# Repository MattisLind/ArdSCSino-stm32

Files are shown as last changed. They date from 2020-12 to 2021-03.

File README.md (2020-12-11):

# ArdSCSino-stm32

The idea and the base code was taken from a project created by Tambo (TNB Seisakusho) (https://twitter.com/h_koma2) ArdSCSino is hardware that reproduces SCSI devices (hard disks) with arduino.

### Setup

I am using Arduino Software (IDE) V1.8.13.
Tools-> Boards-> Board Manager-> Search Filters Search and install "Arduino SAM board (32-bit ARM Cortex-M3)" Select the board "Generic STM32F103C series"

I am using the following as a library.

SDFAT (https://github.com/greiman/SdFat/tree/1.1.4) 

* Make sure to use V1 of SdFat (for example V1.1.4 )
* Make sure to set the #define ENABLE_EXTENDED_TRANSFER_CLASS 1 in SdFatConfig.h

Arduino_STM32 (https://github.com/rogerclarkmelbourne/Arduino_STM32/releases/tag/v1.0.0)

## Enhancements

In the STM32SCSISD folder there is a new PCB which integrates the following features:
* Floppy / AMP / TE connectivity connector.
* Pin headers for serial port, USB, SWD connectors. The use of these are for debugging only and is purely optional.
* Jumpers for RESET and BOOT. Also only needed for debuging.
* Jumpers for and image select. The image select feature allow for selecting one out of four images on the card when the SCSI device is selected.
* Jumpers for unit select. Allow the settig of the SCSI ID. The ID is also used to select one of seven sets of images as defined by the image select above.
* Activity LED pin header.
* Mounting holes.

The firmware (in STM32SCSISD_FW) has been improved by optimizing how data is transfered to the SCSI port. One SCSI transaction is now 1.2 microsseconds and the innerloop consists of 30 instructions. Please make sure that you use -O3 optimizations when compiling the project.

```
arm-none-eabi-g++ -mcpu=cortex-m3 -mthumb ArdSCSinoV2.cpp ../../SdFat/src/FatLib/FatFile.cpp  -I../../Arduino_STM32/STM32F1/libraries/SPI/src/ -I../../Arduino_STM32/STM32F1/system/libmaple/include/ -I../../Arduino_STM32/STM32F1/system/libmaple/ -I../../Arduino_STM32/STM32F1/cores/maple/ -I../../Arduino_STM32/STM32F1/variants/generic_stm32f103c -DMCU_STM32F103C8 -I../../Arduino_STM32/STM32F1/system/libmaple/stm32f1/include/ -I../../SdFat/src/ -DARDUINO -DF_CPU=72000000 -D__arm__ -D__STM32F1__ -Dnullptr=NULL -O3
```

Real life copying of 5 Mbyte file under RT-11 operating system running on a PDP-11/23 CPU takes 23 seconds which is equivalent of 218kbytes/s copying speed. Comparing this with the SCSI2SD v5 adapter gives a 305kbytes/s copying speed. 

The design has also been tested successfully with a Luxor ABC1600 computer.

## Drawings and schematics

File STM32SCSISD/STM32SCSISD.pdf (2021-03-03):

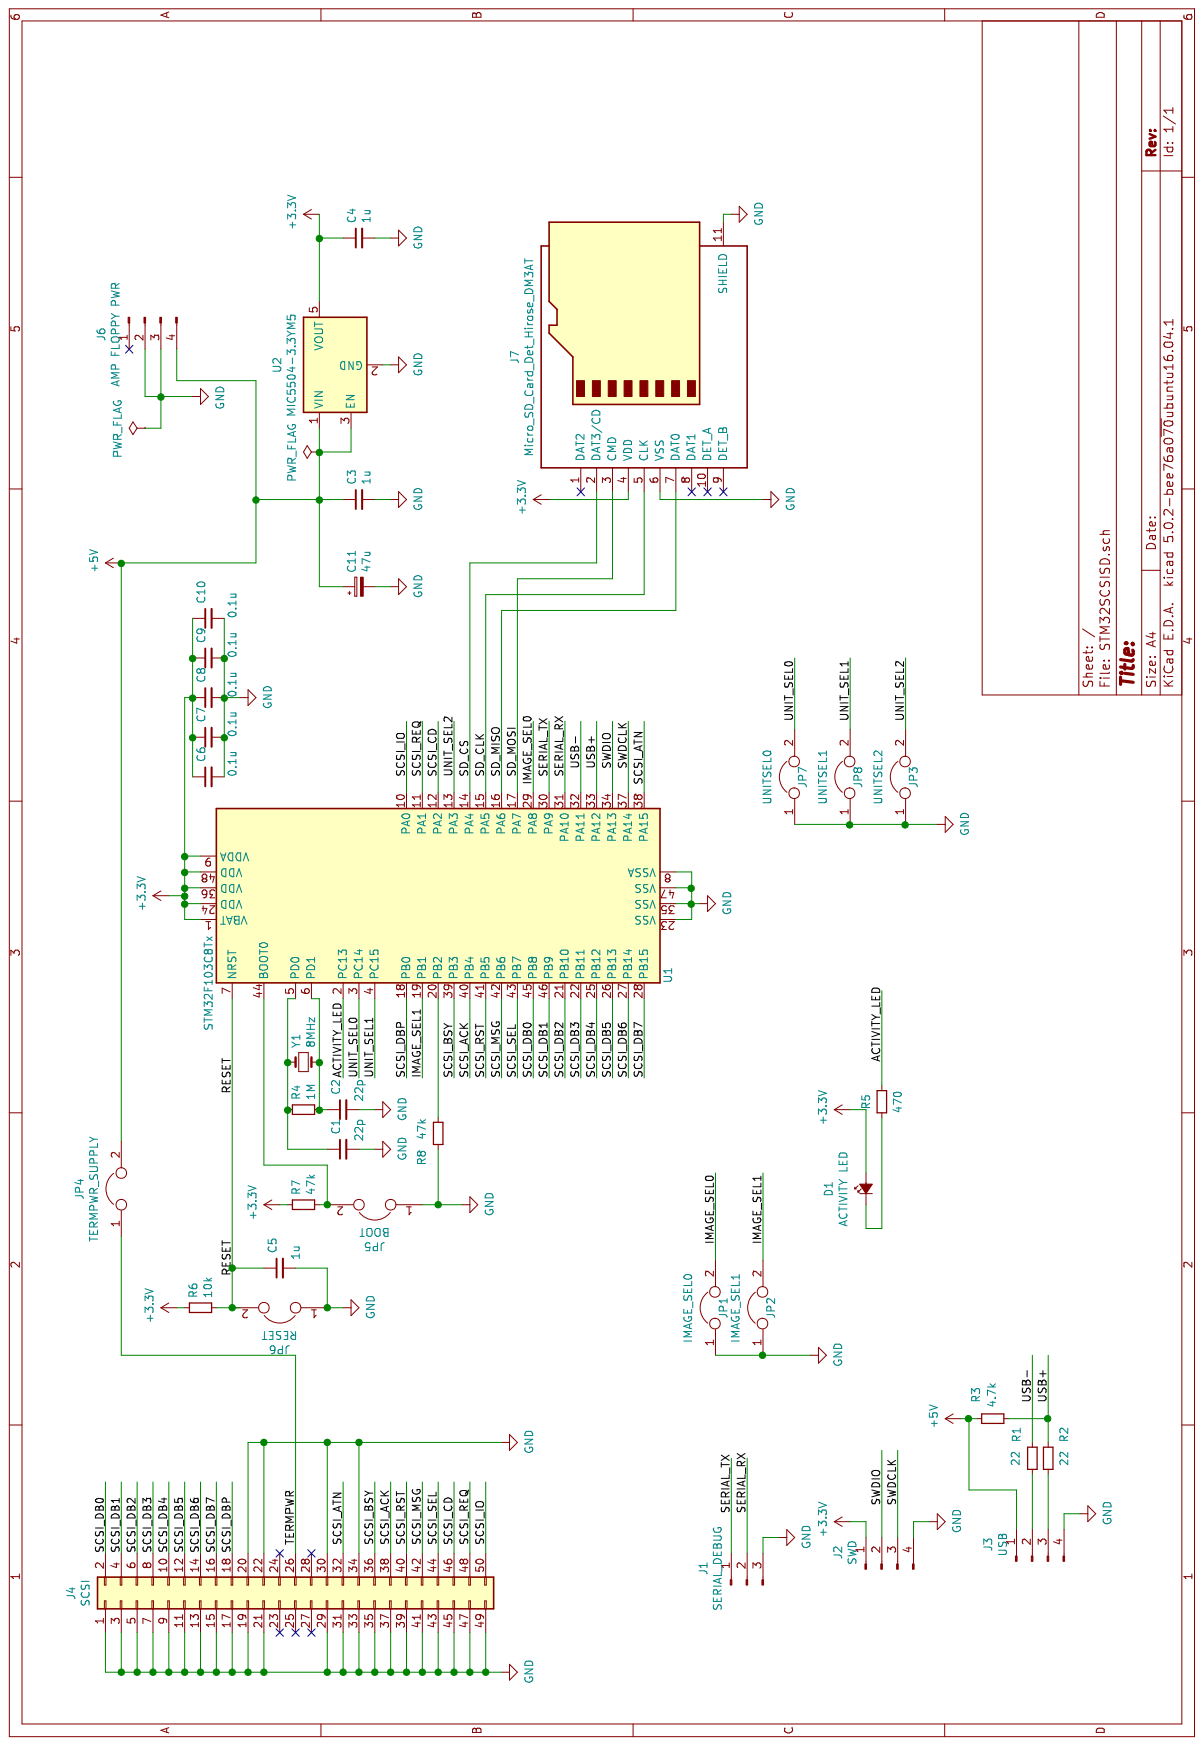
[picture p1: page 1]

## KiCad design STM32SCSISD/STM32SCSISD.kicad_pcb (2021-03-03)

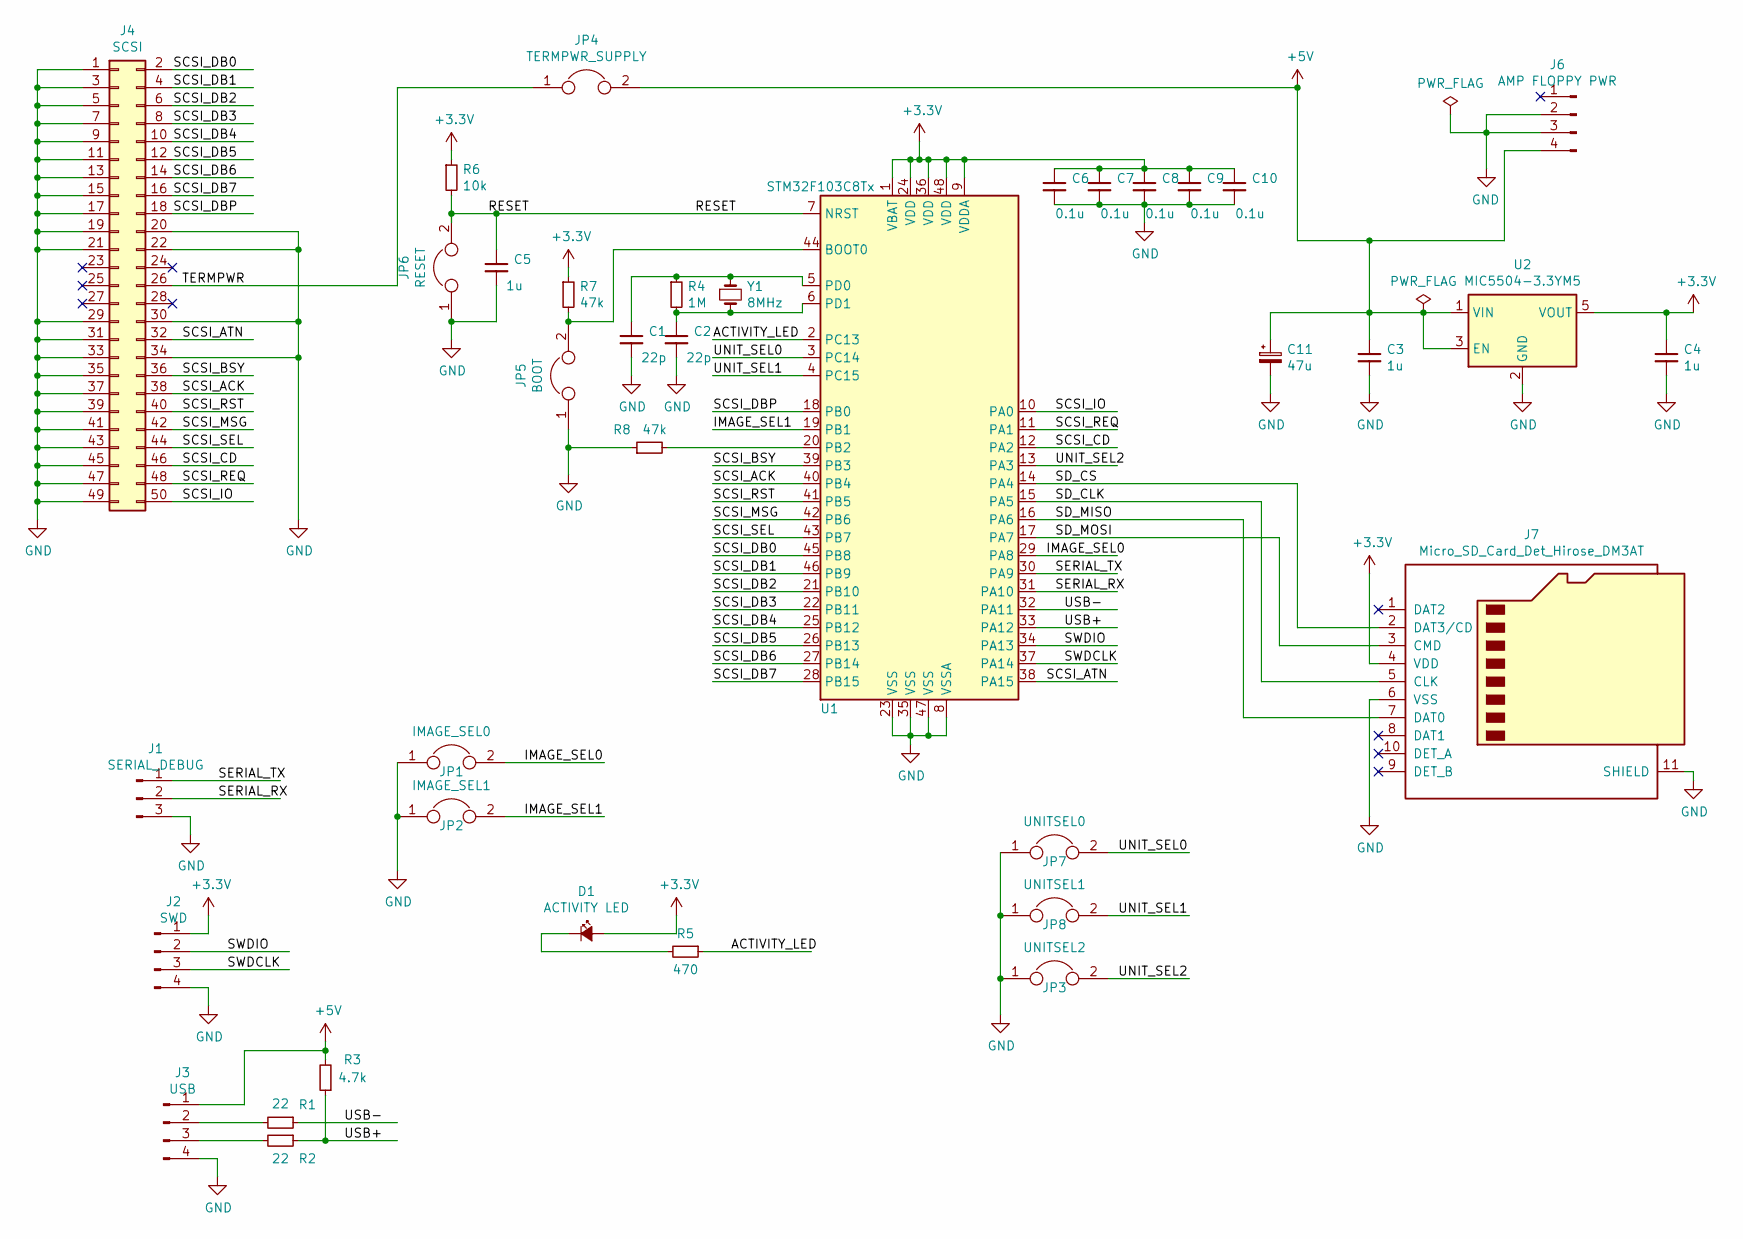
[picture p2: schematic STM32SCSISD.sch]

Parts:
C1, C2: 22p; C_0805_2012Metric
C3, C4, C5: 1u; C_0805_2012Metric
C6, C7, C8, C9, C10: 0.1u; C_0805_2012Metric
C11: 47u; CP_Radial_D5.0mm_P2.50mm
D1: ACTIVITY LED; LED_D5.0mm
J1: SERIAL_DEBUG; PinHeader_1x03_P2.54mm_Vertical
J2: SWD; PinHeader_1x04_P2.54mm_Vertical
J3: USB; PinHeader_1x04_P2.54mm_Vertical
J4: SCSI; IDC-Header_2x25_P2.54mm_Vertical
J6: AMP FLOPPY PWR; TE_MATE-N-LOK_350211-1_1x04_P5.08mm_Vertical
J7: Micro_SD_Card_Det_Hirose_DM3AT; microSD_HC_Hirose_DM3AT-SF-PEJM5
JP1: IMAGE_SEL0; PinHeader_1x02_P2.54mm_Vertical
JP2: IMAGE_SEL1; PinHeader_1x02_P2.54mm_Vertical
JP3: UNITSEL2; PinHeader_1x02_P2.54mm_Vertical
JP4: TERMPWR_SUPPLY; PinHeader_1x02_P2.54mm_Vertical
JP5: BOOT; PinHeader_1x02_P2.54mm_Vertical
JP6: RESET; PinHeader_1x02_P2.54mm_Vertical
JP7: UNITSEL0; PinHeader_1x02_P2.54mm_Vertical
JP8: UNITSEL1; PinHeader_1x02_P2.54mm_Vertical
R1, R2: 22; R_0805_2012Metric_Pad1.15x1.40mm_HandSolder
R3: 4.7k; R_0805_2012Metric_Pad1.15x1.40mm_HandSolder
R4: 1M; R_0805_2012Metric_Pad1.15x1.40mm_HandSolder
R5: 470; R_0805_2012Metric_Pad1.15x1.40mm_HandSolder
R6: 10k; R_0805_2012Metric_Pad1.15x1.40mm_HandSolder
R7, R8: 47k; R_0805_2012Metric_Pad1.15x1.40mm_HandSolder
U1: STM32F103C8Tx; LQFP-48_7x7mm_P0.5mm
U2: MIC5504-3.3YM5; SOT-23-5
Y1: 8MHz; Crystal_HC49-U_Vertical

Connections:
+3V3: C4.1, C6.1, C7.1, C8.1, C9.1, C10.1, D1.2 (A), J2.1, J7.4 (VDD), R6.1, R7.1, U1.1 (VBAT), U1.9 (VDDA), U1.24 (VDD), U1.36 (VDD), U1.48 (VDD), U2.5 (VOUT)
+5V: C3.1, C11.1, J3.1, J6.4, JP4.2, R3.2, U2.1 (VIN), U2.3 (EN)
/ACTIVITY_LED: R5.1, U1.2 (PC13)
/IMAGE_SEL0: JP1.2, U1.29 (PA8)
/IMAGE_SEL1: JP2.2, U1.19 (PB1)
/RESET: C5.1, JP6.2, R6.2, U1.7 (NRST)
/SCSI_ACK: J4.38, U1.40 (PB4)
/SCSI_ATN: J4.32, U1.38 (PA15)
/SCSI_BSY: J4.36, U1.39 (PB3)
/SCSI_CD: J4.46, U1.12 (PA2)
/SCSI_DB0: J4.2, U1.45 (PB8)
/SCSI_DB1: J4.4, U1.46 (PB9)
/SCSI_DB2: J4.6, U1.21 (PB10)
/SCSI_DB3: J4.8, U1.22 (PB11)
/SCSI_DB4: J4.10, U1.25 (PB12)
/SCSI_DB5: J4.12, U1.26 (PB13)
/SCSI_DB6: J4.14, U1.27 (PB14)
/SCSI_DB7: J4.16, U1.28 (PB15)
/SCSI_DBP: J4.18, U1.18 (PB0)
/SCSI_IO: J4.50, U1.10 (PA0)
/SCSI_MSG: J4.42, U1.42 (PB6)
/SCSI_REQ: J4.48, U1.11 (PA1)
/SCSI_RST: J4.40, U1.41 (PB5)
/SCSI_SEL: J4.44, U1.43 (PB7)
/SD_CLK: J7.5 (CLK), U1.15 (PA5)
/SD_CS: J7.2 (DAT3/CD), U1.14 (PA4)
/SD_MISO: J7.7 (DAT0), U1.16 (PA6)
/SD_MOSI: J7.3 (CMD), U1.17 (PA7)
/SERIAL_RX: J1.2, U1.31 (PA10)
/SERIAL_TX: J1.1, U1.30 (PA9)
/SWDCLK: J2.3, U1.37 (PA14)
/SWDIO: J2.2, U1.34 (PA13)
/TERMPWR: J4.26, JP4.1
/UNIT_SEL0: JP7.2, U1.3 (PC14)
/UNIT_SEL1: JP8.2, U1.4 (PC15)
/UNIT_SEL2: JP3.2, U1.13 (PA3)
/USB+: R2.1, R3.1, U1.33 (PA12)
/USB-: R1.1, U1.32 (PA11)
GND: C1.2, C2.2, C3.2, C4.2, C5.2, C6.2, C7.2, C8.2, C9.2, C10.2, C11.2, J1.3, J2.4, J3.4, J4.1, J4.3, J4.5, J4.7, J4.9, J4.11, J4.13, J4.15, J4.17, J4.19, J4.20, J4.21, J4.22, J4.29, J4.30, J4.31, J4.33, J4.34, J4.35, J4.37, J4.39, J4.41, J4.43, J4.45, J4.47, J4.49, J6.2, J6.3, J7.6 (VSS), J7.11 (SHIELD), JP1.1, JP2.1, JP3.1, JP5.1, JP6.1, JP7.1, JP8.1, R8.1, U1.8 (VSSA), U1.23 (VSS), U1.35 (VSS), U1.47 (VSS), U2.2 (GND)
unnamed: C1.1, R4.1, U1.5 (PD0), Y1.1
unnamed: C2.1, R4.2, U1.6 (PD1), Y1.2
unnamed: D1.1 (K), R5.2
unnamed: J3.2, R1.2
unnamed: J3.3, R2.2
unnamed: JP5.2, R7.2, U1.44 (BOOT0)
unnamed: R8.2, U1.20 (PB2)

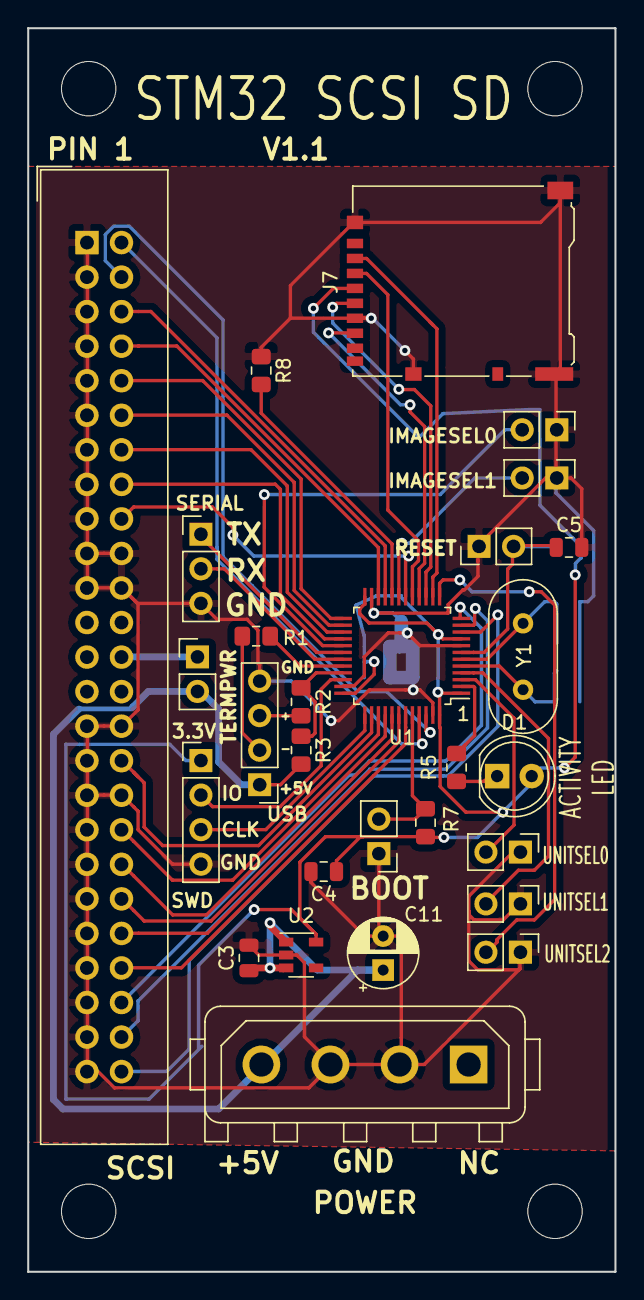
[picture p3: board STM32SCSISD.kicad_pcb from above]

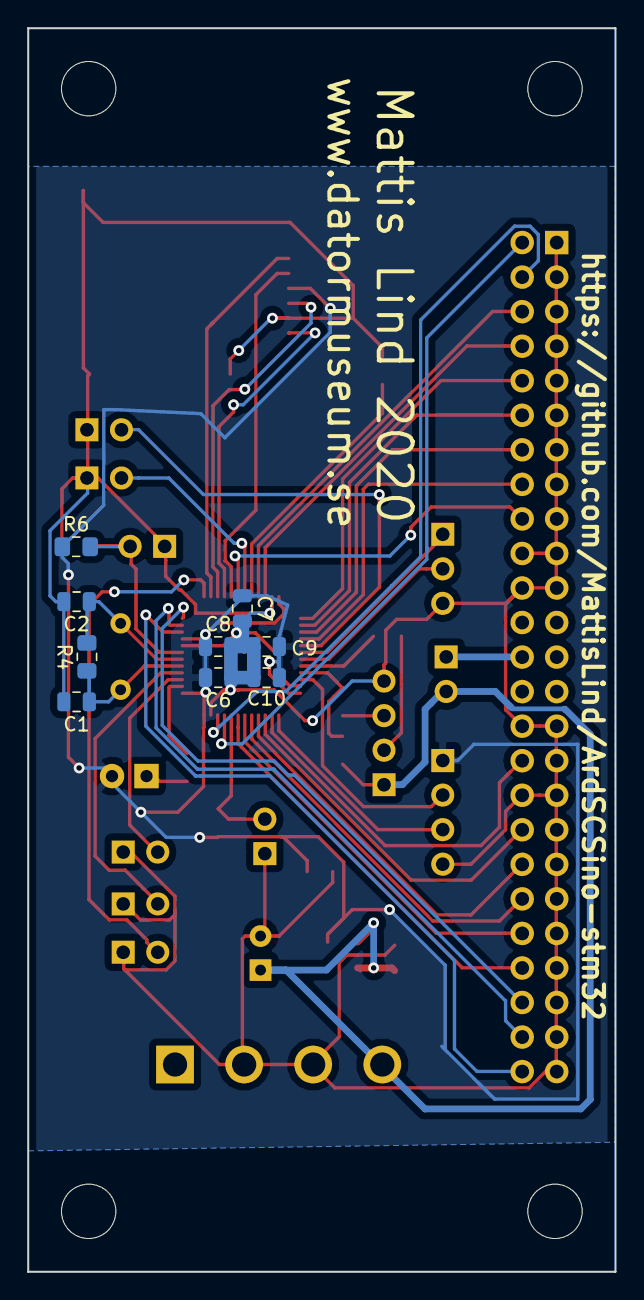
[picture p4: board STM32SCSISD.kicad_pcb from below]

Board: 2 copper layers, 43.2 x 91.4 mm, 37 parts (9 on the bottom side), 46 nets.

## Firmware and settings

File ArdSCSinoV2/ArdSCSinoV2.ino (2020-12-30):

/*
 * SCSI-HDデバイスエミュレータ
 */
#include <SPI.h>
#include "SdFat.h"

//ENABLE_EXTENDED_TRANSFER_CLASSを1に設定する
//libraries/SdFat/SdFatConfig.h
SPIClass SPI_1(1);
SdFatEX  SD(&SPI_1);

#define LOG(XX)     //Serial.print(XX)
#define LOGHEX(XX)  //Serial.print(XX, HEX)
#define LOGN(XX)    //Serial.println(XX)
#define LOGHEXN(XX) //Serial.println(XX, HEX)

#define high 0
#define low 1
#define active   1
#define inactive 0

#define isHigh(XX) ((XX) == high)
#define isLow(XX) ((XX) != high)

#define gpio_mode(pin,val) gpio_set_mode(PIN_MAP[pin].gpio_device, PIN_MAP[pin].gpio_bit, val);
#define gpio_write(pin,val) gpio_write_bit(PIN_MAP[pin].gpio_device, PIN_MAP[pin].gpio_bit, val)
#define gpio_read(pin) gpio_read_bit(PIN_MAP[pin].gpio_device, PIN_MAP[pin].gpio_bit)

//#define DB0       PB8     // SCSI:DB0
//#define DB1       PB9     // SCSI:DB1
//#define DB2       PB10    // SCSI:DB2
//#define DB3       PB11    // SCSI:DB3
//#define DB4       PB12    // SCSI:DB4
//#define DB5       PB13    // SCSI:DB5
//#define DB6       PB14    // SCSI:DB6
//#define DB7       PB15    // SCSI:DB7
//#define DBP       PB0     // SCSI:DBP

#define ATN       PA8      // SCSI:ATN
#define BSY       PA9      // SCSI:BSY
#define ACK       PA10     // SCSI:ACK
#define RST       PA15     // SCSI:RST
#define MSG       PB3      // SCSI:MSG
#define SEL       PB4      // SCSI:SEL
#define CD        PB5      // SCSI:C/D
#define REQ       PB6      // SCSI:REQ
#define IO        PB7      // SCSI:I/O

#define SD_CS     PA4      // SDCARD:CS
#define LED       PC13     // LED

// GPIOレジスタポート
#define PAREG GPIOA->regs
#define PBREG GPIOB->regs

// 仮想ピン（Arduio互換は遅いのでMCU依存にして）
#define PA(BIT)       (BIT)
#define PB(BIT)       (BIT+16)
// 仮想ピンのデコード
#define GPIOREG(VPIN)    ((VPIN)>=16?PBREG:PAREG)
#define BITMASK(VPIN) (1<<((VPIN)&15))

#define vATN       PA(8)      // SCSI:ATN
#define vBSY       PA(9)      // SCSI:BSY
#define vACK       PA(10)     // SCSI:ACK
#define vRST       PA(15)     // SCSI:RST
#define vMSG       PB(3)      // SCSI:MSG
#define vSEL       PB(4)      // SCSI:SEL
#define vCD        PB(5)      // SCSI:C/D
#define vREQ       PB(6)      // SCSI:REQ
#define vIO        PB(7)      // SCSI:I/O
#define vSD_CS     PA(4)      // SDCARD:CS

// SCSI 出力ピン制御 : opendrain active LOW (direct pin drive)
#define SCSI_OUT(VPIN,ACTIVE) { GPIOREG(VPIN)->BSRR = BITMASK(VPIN)<<((ACTIVE)?16:0); }

// SCSI 入力ピン確認(inactive=0,avtive=1)
#define SCSI_IN(VPIN) ((~GPIOREG(VPIN)->IDR>>(VPIN&15))&1)

// GPIO mode
// IN , FLOAT      : 4
// IN , PU/PD      : 8
// OUT, PUSH/PULL  : 3
// OUT, OD         : 1
//#define DB_MODE_OUT 3
#define DB_MODE_OUT 1
#define DB_MODE_IN  8

// DB,DPを出力モードにする
#define SCSI_DB_OUTPUT() { PBREG->CRL=(PBREG->CRL &0xfffffff0)|DB_MODE_OUT; PBREG->CRH = 0x11111111*DB_MODE_OUT; }
// DB,DPを入力モードにする
#define SCSI_DB_INPUT()  { PBREG->CRL=(PBREG->CRL &0xfffffff0)|DB_MODE_IN ; PBREG->CRH = 0x11111111*DB_MODE_IN;  }

// BSYだけ出力をON にする
#define SCSI_BSY_ACTIVE()      { gpio_mode(BSY, GPIO_OUTPUT_OD); SCSI_OUT(vBSY,  active) }
// BSY,REQ,MSG,CD,IO 出力をON にする (ODの場合は変更不要）
#define SCSI_TARGET_ACTIVE()   { }
// BSY,REQ,MSG,CD,IO 出力をOFFにする、BSYは最後、入力に
#define SCSI_TARGET_INACTIVE() { SCSI_OUT(vREQ,inactive); SCSI_OUT(vMSG,inactive); SCSI_OUT(vCD,inactive);SCSI_OUT(vIO,inactive); SCSI_OUT(vBSY,inactive); gpio_mode(BSY, GPIO_INPUT_PU); }



#define SCSIID    0                 // SCSI-ID 

#define BLOCKSIZE 512               // 1BLOCKサイズ
uint8_t       m_senseKey = 0;       //センスキー
volatile bool m_isBusReset = false; //バスリセット

#define HDIMG_FILE "HD.HDS"         // HDイメージファイル名
File          m_file;               // ファイルオブジェクト
uint32_t      m_fileSize;           // ファイルサイズ
byte          m_buf[BLOCKSIZE];     // 汎用バッファ

int           m_msc;
bool          m_msb[256];

// パリティービット生成
#define PTY(V)   (1^((V)^((V)>>1)^((V)>>2)^((V)>>3)^((V)>>4)^((V)>>5)^((V)>>6)^((V)>>7))&1)

// データバイト to BSRRレジスタ設定値変換テーブル
// BSRR[31:24] =  DB[7:0]
// BSRR[   16] =  PTY(DB)
// BSRR[15: 8] = ~DB[7:0]
// BSRR[    0] = ~PTY(DB)

// DBPのセット、REQ=inactiveにする
#define DBP(D)    ((((((uint32_t)(D)<<8)|PTY(D))*0x00010001)^0x0000ff01)|BITMASK(vREQ))

#define DBP8(D)   DBP(D),DBP(D+1),DBP(D+2),DBP(D+3),DBP(D+4),DBP(D+5),DBP(D+6),DBP(D+7)
#define DBP32(D)  DBP8(D),DBP8(D+8),DBP8(D+16),DBP8(D+24)

// DBのセット,DPのセット,REQ=H(inactrive) を同時に行うBSRRレジスタ制御値
static const uint32_t db_bsrr[256]={
  DBP32(0x00),DBP32(0x20),DBP32(0x40),DBP32(0x60),
  DBP32(0x80),DBP32(0xA0),DBP32(0xC0),DBP32(0xE0)
};
// パリティービット取得
#define PARITY(DB) (db_bsrr[DB]&1)


/*
 * IO読み込み.
 */
inline byte readIO(void)
{
  //GPIO(SCSI BUS)初期化
  //ポート設定レジスタ（下位）
//  GPIOB->regs->CRL |= 0x000000008; // SET INPUT W/ PUPD on PAB-PB0
  //ポート設定レジスタ（上位）
  
//  GPIOB->regs->ODR = 0x0000FF00; // SET PULL-UPs on PB15-PB8
  //ポート入力データレジスタ
/*  uint32 ret = GPIOB->regs->IDR;
  byte bret =  0x00;
  bret |= (!(ret & (1<<15))) << 7;
  bret |= (!(ret & (1<<14))) << 6;
  bret |= (!(ret & (1<<13))) << 5;
  bret |= (!(ret & (1<<12))) << 4;
  bret |= (!(ret & (1<<11))) << 3;
  bret |= (!(ret & (1<<10))) << 2;
  bret |= (!(ret & (1<<9)))  << 1;
  bret |= (!(ret & (1<<8)))  << 0;
  return bret; */
  return 0xff & (~(GPIOB->regs->IDR >> 8));
}

/* 
 * IO書き込み.
 */
inline void writeIO(byte v)
{
  //GPIO(SCSI BUS)初期化
  //ポート設定レジスタ（下位）
//  GPIOB->regs->ODR != 0x0000FF00; // SET PULL-UPs on PB15-PB8
/*  LOGHEXN((v));
  LOGHEXN((GPIOB->regs->ODR & 0x00ff));
  LOGHEXN((  (GPIOB->regs->ODR & 0x00ff) | (0xff00 & (v <<8)))); */
GPIOB->regs->ODR = (GPIOB->regs->ODR & 0x00fe) | (0xff00 & ((~v) <<8) )| parity(v) ;
/*
  if(!parity(v)) {
    GPIOB->regs->BRR = 1;
  } else {
    GPIOB->regs->BSRR = 1;
  }
*/
/*
  uint32 retL =  0x00;
  uint32 retH =  0x00;
  LOGHEXN(v);
  if(!parity(v)) {
    retL |= (1<<0);
  } else {
    retH |= (1<<0);
  }
  /*
  if(v & ( 1 << 7 )) {
    retL |= (1<<15);
  } else {
    retH |= (1<<15);
  }  
  if(v & ( 1 << 6 )) {
    retL |= (1<<14);
  } else {
    retH |= (1<<14);
  }
  if(v & ( 1 << 5 )) {
    retL |= (1<<13);
  } else {
    retH |= (1<<13);
  }
  if(v & ( 1 << 4 )) {
    retL |= (1<<12);
  } else {
    retH |= (1<<12);
  }
  if(v & ( 1 << 3 )) {
    retL |= (1<<11);
  } else {
    retH |= (1<<11);
  }
  if(v & ( 1 << 2 )) {
    retL |= (1<<10);
  } else {
    retH |= (1<<10);
  }
  if(v & ( 1 << 1 )) {
    retL |= (1<<9);
  } else {
    retH |= (1<<9);
  }
  if(v & ( 1 << 0 )) {
    retL |= (1<<8);
  } else {
    retH |= (1<<8);
  } */
  /*retL |= v<<8;
  retH |= 0xffff & ((~v)<<8); 
  LOGHEXN(retL);
  LOGHEXN(retH);
  //ビットがLOWに設定される
  GPIOB->regs->BRR = retL ;
  // ビットがHIGHに設定される
  GPIOB->regs->BSRR = retH ; */ 
}

/*
 * 初期化.
 *  パリティチェック
 */
inline int parity(byte val) {
  val ^= val >> 4;
  val ^= val >> 2;
  val ^= val >> 1;

  return val & 0x00000001;
}

/*
 * 初期化.
 *  バスの初期化、PINの向きの設定を行う
 */
void setup()
{
  // PA15 / PB3 / PB4 が使えない
  // But only disable JTAG not SWD
  afio_cfg_debug_ports(AFIO_DEBUG_SW_ONLY);

  //シリアル初期化
  //Serial.begin(9600);
  //while (!Serial);

  //PINの初期化
  gpio_mode(LED, GPIO_OUTPUT_OD);
  gpio_write(LED, low);

 //GPIO(SCSI BUS)初期化
  //ポート設定レジスタ（下位）
//  GPIOB->regs->CRL |= 0x000000008; // SET INPUT W/ PUPD on PAB-PB0
  //ポート設定レジスタ（上位）
  GPIOB->regs->CRH = 0x88888888; // SET INPUT W/ PUPD on PB15-PB8
//  GPIOB->regs->ODR = 0x0000FF00; // SET PULL-UPs on PB15-PB8

  gpio_mode(ATN, GPIO_INPUT_PU);
  gpio_mode(BSY, GPIO_INPUT_PU);
  gpio_mode(ACK, GPIO_INPUT_PU);
  gpio_mode(RST, GPIO_INPUT_PU);
  gpio_mode(SEL, GPIO_INPUT_PU);
  
  gpio_mode(MSG, GPIO_OUTPUT_PP);
  gpio_mode(CD, GPIO_OUTPUT_PP);
  gpio_mode(REQ, GPIO_OUTPUT_PP);
  gpio_mode(IO, GPIO_OUTPUT_PP);

  gpio_write(MSG, low);
  gpio_write(CD, low);
  gpio_write(REQ, low);
  gpio_write(IO, low);

  //RSTピンの状態がHIGHからLOWに変わったときに発生
  attachInterrupt(PIN_MAP[RST].gpio_bit, onBusReset, FALLING);
  
  if(!SD.begin(SD_CS,SPI_FULL_SPEED)) {
    Serial.println("SD initialization failed!");
    onFalseInit();
  }
  //HDイメージファイル
  m_file = SD.open(HDIMG_FILE, O_RDWR);
  if(!m_file) {
    Serial.println("Error: open hdimg");
    onFalseInit();
  }
  m_fileSize = m_file.size();
  Serial.println("Found Valid HD Image File.");
  Serial.print(m_fileSize);
  Serial.println("byte");
  Serial.print(m_fileSize / 1024);
  Serial.println("KB");
  Serial.print(m_fileSize / 1024 / 1024);
  Serial.println("MB");
}

/*
 * 初期化失敗.
 */
void onFalseInit(void)
{
  while(true) {
    gpio_write(LED, high);
    delay(500); 
    gpio_write(LED, low);
    delay(500);
  }
}

/*
 * バスリセット割り込み.
 */
void onBusReset(void)
{
  if(isHigh(gpio_read(RST))) {
    delayMicroseconds(20);
    if(isHigh(gpio_read(RST))) {
      LOGN("BusReset!");
      m_isBusReset = true;
    }
  }
}

/*
 * ハンドシェイクで読み込む.
 */
inline byte readHandshake(void)
{
  
  GPIOB->regs->BRR = 1 << 6;
  while(GPIOA->regs->IDR & (1 << 10)) {
    if(m_isBusReset) {
      return 0;
    }
  }
  byte r = readIO();
  GPIOB->regs->BSRR = 1<<6;
  while(!(GPIOA->regs->IDR & (1<<10))) {
    if(m_isBusReset) {
      return 0;
    }
  }
  return r;  
}

/*
 * ハンドシェイクで書込み.
 */
inline void writeHandshake(byte d)
{
  writeIO(d);
  GPIOB->regs->BRR = 1 << 6;
  //gpio_write(REQ, high);
  while(GPIOA->regs->IDR & (1 << 10)) {
  //while(isLow(gpio_read(ACK))) {
    if(m_isBusReset) {
      return;
    }
  }
  GPIOB->regs->BSRR = 1<<6;
  //gpio_write(REQ, low);
  //while(isHigh(gpio_read(ACK))) {
  while(!(GPIOA->regs->IDR & (1<<10))) {
    if(m_isBusReset) {
      return;
    }
  }
}

/*
 * データインフェーズ.
 *  データ配列 p を len バイト送信する。
 */
void writeDataPhase(int len, byte* p)
{
  LOGN("DATAIN PHASE");
  gpio_write(MSG, low);
  gpio_write(CD, low);
  gpio_write(IO, high);
  GPIOB->regs->CRL |= 0x00000003; // SET OUTPUT W/ PUPD on PA7-PB0 50MHz
  //ポート設定レジスタ（上位）
  GPIOB->regs->CRH = 0x33333333; // SET OUTPUT W/ PUPD on PB15-PB8 50MHz

  for (int i = 0; i < len; i++) {
    if(m_isBusReset) {
      return;
    }
    writeHandshake(p[i]);
  }
}

/*

void writeDataPhaseSD(uint32_t adds, uint32_t len)
{
  LOGN("DATAIN PHASE(SD)");
  uint32_t pos = adds * BLOCKSIZE;
  m_file.seek(pos);

  SCSI_OUT(vMSG,inactive) //  gpio_write(MSG, low);
  SCSI_OUT(vCD ,inactive) //  gpio_write(CD, low);
  SCSI_OUT(vIO ,  active) //  gpio_write(IO, high);
  for(uint32_t i = 0; i < len; i++) {
      // 非同期リードにすれば速くなるんだけど...
    m_file.read(m_buf, BLOCKSIZE);


//#define REQ_ON() SCSI_OUT(vREQ,active)
#define REQ_ON() (*db_dst = BITMASK(vREQ)<<16)
#define FETCH_SRC()   (src_byte = *srcptr++)
#define FETCH_BSRR_DB() (bsrr_val = bsrr_tbl[src_byte])
#define REQ_OFF_DB_SET(BSRR_VAL) *db_dst = BSRR_VAL
#define WAIT_ACK_ACTIVE()   while(!m_isBusReset && !SCSI_IN(vACK))
#define WAIT_ACK_INACTIVE() do{ if(m_isBusReset) return; }while(SCSI_IN(vACK)) 

    SCSI_DB_OUTPUT()
    register byte *srcptr= m_buf;                 // ソースバッファ
    register byte *endptr= m_buf +  BLOCKSIZE; // 終了ポインタ
    
    /*register*/  /*byte src_byte;                       // 送信データバイト
    register const uint32_t *bsrr_tbl = db_bsrr;  // BSRRに変換するテーブル
    register uint32_t bsrr_val;                   // 出力するBSRR値(DB,DBP,REQ=ACTIVE)
    register volatile uint32_t *db_dst = &(GPIOB->regs->BSRR); // 出力ポート

    // prefetch & 1st out
    src_byte = *srcptr++;
    (bsrr_val = bsrr_tbl[src_byte];
    *db_dst = bsrr_val;
    // DB.set to REQ.F setup 100ns max (DTC-510B)
    // ここには多少のウェイトがあったほうがいいかも
    //　WAIT_ACK_INACTIVE();
    do{
      // 0
      *db_dst = BITMASK(vREQ)<<16;
      src_byte = *srcptr++;
      bsrr_val = bsrr_tbl[src_byte];
      while(!m_isBusReset && !SCSI_IN(vACK));
      // ACK.F  to REQ.R       500ns typ. (DTC-510B)
      *db_dst = bsrr_val;
      do{ if(m_isBusReset) return; }while(SCSI_IN(vACK));
      // 1
      REQ_ON();
      FETCH_SRC();
      FETCH_BSRR_DB();
      WAIT_ACK_ACTIVE();
      REQ_OFF_DB_SET(bsrr_val);
      WAIT_ACK_INACTIVE();
      // 2
      REQ_ON();
      FETCH_SRC();
      FETCH_BSRR_DB();
      WAIT_ACK_ACTIVE();
      REQ_OFF_DB_SET(bsrr_val);
      WAIT_ACK_INACTIVE();
      // 3
      REQ_ON();
      FETCH_SRC();
      FETCH_BSRR_DB();
      WAIT_ACK_ACTIVE();
      REQ_OFF_DB_SET(bsrr_val);
      WAIT_ACK_INACTIVE();
      // 4
      REQ_ON();
      FETCH_SRC();
      FETCH_BSRR_DB();
      WAIT_ACK_ACTIVE();
      REQ_OFF_DB_SET(bsrr_val);
      WAIT_ACK_INACTIVE();
      // 5
      REQ_ON();
      FETCH_SRC();
      FETCH_BSRR_DB();
      WAIT_ACK_ACTIVE();
      REQ_OFF_DB_SET(bsrr_val);
      WAIT_ACK_INACTIVE();
      // 6
      REQ_ON();
      FETCH_SRC();
      FETCH_BSRR_DB();
      WAIT_ACK_ACTIVE();
      REQ_OFF_DB_SET(bsrr_val);
      WAIT_ACK_INACTIVE();
      // 7
      REQ_ON();
      FETCH_SRC();
      FETCH_BSRR_DB();
      WAIT_ACK_ACTIVE();
      REQ_OFF_DB_SET(bsrr_val);
      WAIT_ACK_INACTIVE();
    }while(srcptr < endptr);
    SCSI_DB_INPUT()
  }
}
*/
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
void loop() 
{
  int sts = 0;
  int msg = 0;

  //BSY,SELが+はバスフリー
  // セレクションチェック
  // BSYが-の間ループ
  if(isHigh(gpio_read(BSY))) {
    return;
  }
  // SELが+の間ループ
  if(isLow(gpio_read(SEL))) {
    return;
  }
  // BSY+ SEL-
  GPIOB->regs->CRH = 0x88888888; // SET INPUT W/ PUPD on PB15-PB8
  byte db = readIO();  
  if((db & (1 << SCSIID)) == 0) {
    return;
  }

  LOGN("Selection");
  m_isBusReset = false;
  // セレクトされたらBSYを-にする
  gpio_mode(BSY, GPIO_OUTPUT_PP);
  gpio_write(BSY, high);
  while(isHigh(gpio_read(SEL))) {
    if(m_isBusReset) {
      goto BusFree;
    }
  }
  if(isHigh(gpio_read(ATN))) {
    bool syncenable = false;
    int syncperiod = 50;
    int syncoffset = 0;
    m_msc = 0;
    memset(m_msb, 0x00, sizeof(m_msb));
    while(isHigh(gpio_read(ATN))) {
      MsgOut2();
    }
    for(int i = 0; i < m_msc; i++) {
      // ABORT
      if (m_msb[i] == 0x06) {
        goto BusFree;
      }
      // BUS DEVICE RESET
      if (m_msb[i] == 0x0C) {
        syncoffset = 0;
        goto BusFree;
      }
      // IDENTIFY
      if (m_msb[i] >= 0x80) {
      }
      // 拡張メッセージ
      if (m_msb[i] == 0x01) {
        // 同期転送が可能な時だけチェック
        if (!syncenable || m_msb[i + 2] != 0x01) {
          MsgIn2(0x07);
          break;
        }
        // Transfer period factor(50 x 4 = 200nsに制限)
        syncperiod = m_msb[i + 3];
        if (syncperiod > 50) {
          syncoffset = 50;
        }
        // REQ/ACK offset(16に制限)
        syncoffset = m_msb[i + 4];
        if (syncoffset > 16) {
          syncoffset = 16;
        }
        // STDR応答メッセージ生成
        MsgIn2(0x01);
        MsgIn2(0x03);
        MsgIn2(0x01);
        MsgIn2(syncperiod);
        MsgIn2(syncoffset);
        break;
      }
    }
  }

  LOGN("Command");
  gpio_write(MSG, low);
  gpio_write(CD, high);
  gpio_write(IO, low);
  GPIOB->regs->CRH = 0x88888888; // SET INPUT W/ PUPD on PB15-PB8
  int len;
  byte cmd[12];
  cmd[0] = readHandshake();
  LOGHEX(cmd[0]);
  len = 1;
  switch(cmd[0] >> 5) {
  case 0b000:
    len = 6;
    break;
  case 0b001:
    len = 10;
    break;
  case 0b010:
    len = 10;
    break;
  case 0b101:
    len = 12;
    break;
  default:
    break;
  }
  GPIOB->regs->CRH = 0x88888888; // SET INPUT W/ PUPD on PB15-PB8
  for(int i = 1; i < len; i++ ) {
    cmd[i] = readHandshake();
    LOGHEX(cmd[i]);
  }
  LOGN("");

  switch(cmd[0]) {
  case 0x00:
    LOGN("[Test Unit]");
    break;
  case 0x01:
    LOGN("[Rezero Unit]");
    break;
  case 0x03:
    LOGN("[RequestSense]");
    onRequestSenseCommand(cmd[4]);
    break;
  case 0x04:
    LOGN("[FormatUnit]");
    break;
  case 0x06:
    LOGN("[FormatUnit]");
    break;
  case 0x07:
    LOGN("[ReassignBlocks]");
    break;
  case 0x08:
    LOGN("[Read6]");
    sts = onReadCommand((((uint32_t)cmd[1] & 0x1F) << 16) | ((uint32_t)cmd[2] << 8) | cmd[3], (cmd[4] == 0) ? 0x100 : cmd[4]);
    break;
  case 0x0A:
    LOGN("[Write6]");
    sts = onWriteCommand((((uint32_t)cmd[1] & 0x1F) << 16) | ((uint32_t)cmd[2] << 8) | cmd[3], (cmd[4] == 0) ? 0x100 : cmd[4]);
    break;
  case 0x0B:
    LOGN("[Seek6]");
    break;
  case 0x12:
    LOGN("[Inquiry]");
    onInquiryCommand(cmd[4]);
    break;
  case 0x1A:
    LOGN("[ModeSense6]");
    onModeSenseCommand(cmd[1]&0x80, cmd[2] & 0x3F, cmd[4]);
    break;
  case 0x1B:
    LOGN("[StartStopUnit]");
    break;
  case 0x1E:
    LOGN("[PreAllowMed.Removal]");
    break;
  case 0x25:
    LOGN("[ReadCapacity]");
    onReadCapacityCommand(cmd[8]);
    break;
  case 0x28:
    LOGN("[Read10]");
    sts = onReadCommand(((uint32_t)cmd[2] << 24) | ((uint32_t)cmd[3] << 16) | ((uint32_t)cmd[4] << 8) | cmd[5], ((uint32_t)cmd[7] << 8) | cmd[8]);
    break;
  case 0x2A:
    LOGN("[Write10]");
    sts = onWriteCommand(((uint32_t)cmd[2] << 24) | ((uint32_t)cmd[3] << 16) | ((uint32_t)cmd[4] << 8) | cmd[5], ((uint32_t)cmd[7] << 8) | cmd[8]);
    break;
  case 0x2B:
    LOGN("[Seek10]");
    break;
  case 0x5A:
    LOGN("[ModeSense10]");
    onModeSenseCommand(cmd[1] & 0x80, cmd[2] & 0x3F, ((uint32_t)cmd[7] << 8) | cmd[8]);
    break;
  default:
    LOGN("[*Unknown]");
    sts = 2;
    m_senseKey = 5;
    break;
  }
  if(m_isBusReset) {
     goto BusFree;
  }

  LOGN("Sts");
  gpio_write(MSG, low);
  gpio_write(CD, high);
  gpio_write(IO, high);
    GPIOB->regs->CRL |= 0x00000003; // SET OUTPUT W/ PUPD on PA7-PB0 50MHz
  //ポート設定レジスタ（上位）
  GPIOB->regs->CRH = 0x33333333; // SET OUTPUT W/ PUPD on PB15-PB8 50MHz

  writeHandshake(sts);
  if(m_isBusReset) {
     goto BusFree;
  }

  LOGN("MsgIn");
  gpio_write(MSG, high);
  gpio_write(CD, high);
  gpio_write(IO, high);
    GPIOB->regs->CRL |= 0x00000003; // SET OUTPUT W/ PUPD on PA7-PB0 50MHz
  //ポート設定レジスタ（上位）
  GPIOB->regs->CRH = 0x33333333; // SET OUTPUT W/ PUPD on PB15-PB8 50MHz

  writeHandshake(msg);

BusFree:
  LOGN("BusFree");
  m_isBusReset = false;
  gpio_write(REQ, low);
  gpio_write(MSG, low);
  gpio_write(CD, low);
  gpio_write(IO, low);
//  gpio_write(BSY, low);
  gpio_mode(BSY, GPIO_INPUT_PU);
}

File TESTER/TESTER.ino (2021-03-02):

/*

TESTER

Connect 
IMAGE_SEL0 - IMAGE_SEL1
UNIT_SEL1 - UNIT_SEL2
UNIT_SEL0 - ACTIVITY_LED
SCSI DBP (18) - SCSI ATN (32)
SCSI DB7 (16) - SCSI BSY (36)
SCSI DB6 (14) - SCSI ACK (38)
SCSI DB5 (12) - SCSI RST (40)
SCSI DB4 (10) - SCSI MSG (42)
SCSI DB3 (8)  - SCSI SEL (44)
SCSI DB2 (6)  - SCSI CD  (46)
SCSI DB1 (4) -  SCSI IO  (50)
SCSI DB0 (2) -  SCSI REQ (48)

*/

// the setup function runs once when you press reset or power the board
void setup() {
  // initialize digital pin LED_BUILTIN as an output.
  //pinMode(LED_BUILTIN, OUTPUT);
  Serial.begin(9600);
  afio_cfg_debug_ports(AFIO_DEBUG_SW_ONLY);
}

bool testPins(int pinOne, int pinTwo, char * str, bool debug) {
  pinMode(pinOne, OUTPUT);
  pinMode(pinTwo, INPUT);
  digitalWrite(pinOne, HIGH);
  delay(1);  
  if (digitalRead(pinTwo) == HIGH) { 
    if (debug) {
      Serial.print(str);
      Serial.println(" HIGH OK");
    }
  } else {
    Serial.print(str);
    Serial.println(" HIGH NOT OK");
  }
  digitalWrite(pinOne, LOW);
  delay(1); 
  if (digitalRead(pinTwo) == LOW) {
    if (debug) { 
      Serial.print(str);
      Serial.println(" LOW OK");
    }
  } else {
    Serial.print(str);
    Serial.println(" LOW NOT OK");
  }
  pinMode(pinTwo, OUTPUT);
  pinMode(pinOne, INPUT);
  digitalWrite(pinTwo, HIGH);
  delay(1);
  
  if (digitalRead(pinOne) == HIGH) {
    if (debug) { 
      Serial.print(str);
      Serial.println(" HIGH OK");
    }
  } else {
    Serial.print(str);
    Serial.println(" HIGH NOT OK");
  }
  digitalWrite(pinTwo, LOW);
  delay(1);
  
  if (digitalRead(pinOne) == LOW) {
    if (debug) { 
      Serial.print(str);
      Serial.println(" LOW OK");
    }
  } else {
    Serial.print(str);
    Serial.println(" LOW NOT OK");
  }
}

// the loop function runs over and over again forever
void loop() {
  Serial.println("START");
  //digitalWrite(LED_BUILTIN, HIGH);   // turn the LED on (HIGH is the voltage level)
  delay(1000);                       // wait for a second
  testPins(PB9, PA0, "PA0/PB9", false);
  testPins(PB8, PA1, "PA1/PB8", false);
  testPins(PB10, PA2, "PA2/PB10", false);
  testPins(PB11, PB7, "PB7/PB11", false);
  testPins(PB12, PB6, "PB12/PB6", false);
  testPins(PB13, PB5, "PB13/PB5", false);
  testPins(PB14, PB4, "PB14/PB4", false);
  testPins(PB15, PB3, "PB15/PB3", false);
  testPins(PB0, PA15, "PB0/PA15", false);
  testPins(PB1, PA8, "PB1/PA8", false);
  testPins(PA3, PC15, "PA3/PC15", false);
  testPins(PC13, PC14, "PC13/PC14", false);
  Serial.println("STOP");
  //digitalWrite(LED_BUILTIN, LOW);    // turn the LED off by making the voltage LOW
  delay(1000);                       // wait for a second
}

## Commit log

2020-11-28 Started designing a new PCB.
    [STM32SCSISD.kicad_pcb, STM32SCSISD.sch]
2020-11-29 Pre-review of schematic.
    [STM32SCSISD.sch]
2020-11-29 Added a modified firmware adapted to the new PCB.
2020-12-04 Hope this board looks nice!
    [STM32SCSISD-B.Cu.gbr, STM32SCSISD-B.Mask.gbr, STM32SCSISD-B.SilkS.gbr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]
2020-12-26 First version that worked on the new hardware. Two datasignals was interchanged by mistake and required a software change.
    [STM32SCSISD_FW.ino]
2020-12-26 Simple test software that loops all signals to check for soldering errors
    [TESTER.ino]
2020-12-26 Changed hardware to fix the problem instead since it is best longterm.
    [STM32SCSISD_FW.ino]
2020-12-26 Blinking LED due to different error conditions and once when starting.
    [STM32SCSISD_FW.ino]
2020-12-27 Fixed the two SCSI databus bit that was mixed up. Added a 5mm LED instead of connector.
    [STM32SCSISD.sch]
2020-12-27 Fixed the layout so that now it in sync with schematic. DB0 and DB1 is now corrected.
    [STM32SCSISD-B.Cu.gbr, STM32SCSISD-B.Mask.gbr, STM32SCSISD-B.SilkS.gbr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]
2020-12-27 Moved the mounting holes a bit and made sure the filled area didn't enter the area of the mounting holes.
    [STM32SCSISD-B.Cu.gbr, STM32SCSISD-B.Mask.gbr, STM32SCSISD-B.SilkS.gbr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]
2020-12-29 Testing optimizations. New WritePhaseSD creates an instability which refuses it to read correctly some times. Going back to old code always work
    [ArdSCSinoV2.ino]
2020-12-30 8 transaction and added one missing handlimg of busreset. Down to 5.6 us for 8 cycles
    [ArdSCSinoV2.ino]
2021-03-03 Added version 1.1 in the silkscreen.
    [STM32SCSISD-B.Cu.gbr, STM32SCSISD-B.Mask.gbr, STM32SCSISD-B.SilkS.gbr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]
